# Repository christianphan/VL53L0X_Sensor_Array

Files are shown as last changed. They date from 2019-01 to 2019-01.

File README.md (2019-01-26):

# VL53L0X_Sensor_Array
Schematic and Cad file for array of VL53L0X for proximity sensing applications

This PCB combines 5 VL53L0X sensors adjacent next to each other to detect motion and finger gestures. An I2C multiplexor is also in the PCB to control the 5 sensors over I2C.

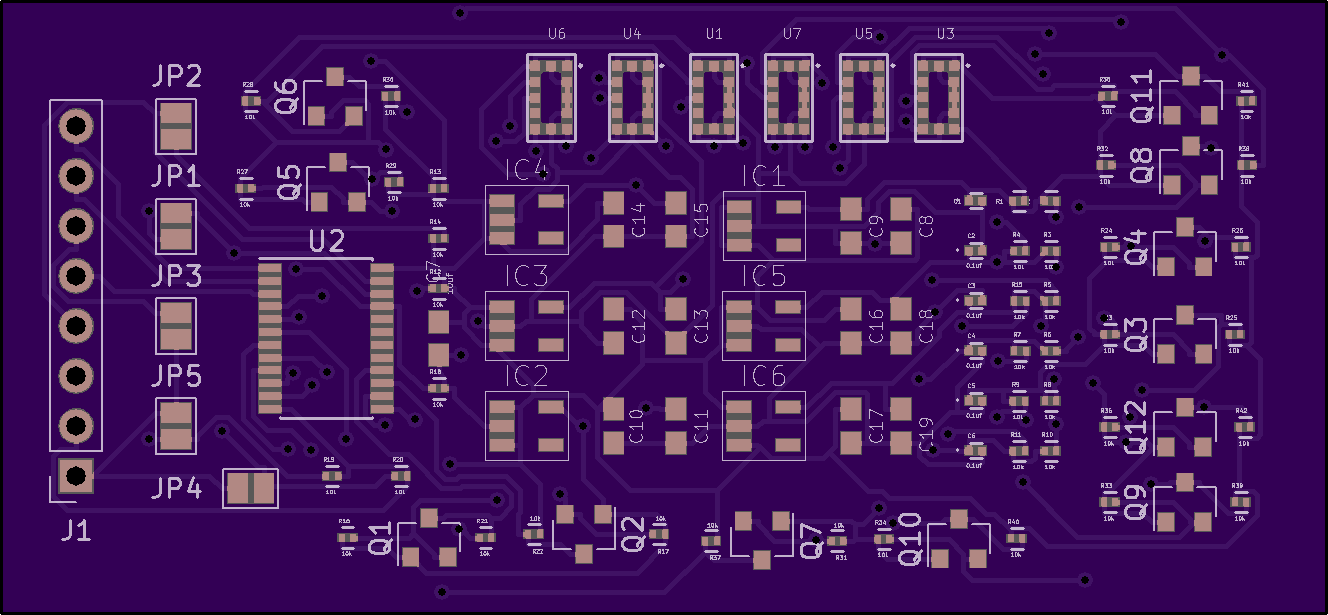
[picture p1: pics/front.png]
Front of PCB


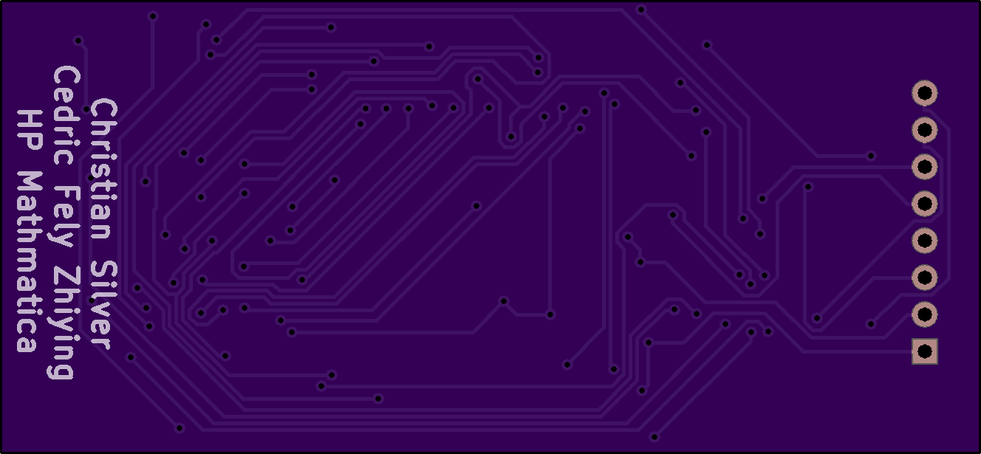
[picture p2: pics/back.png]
Back of PCB


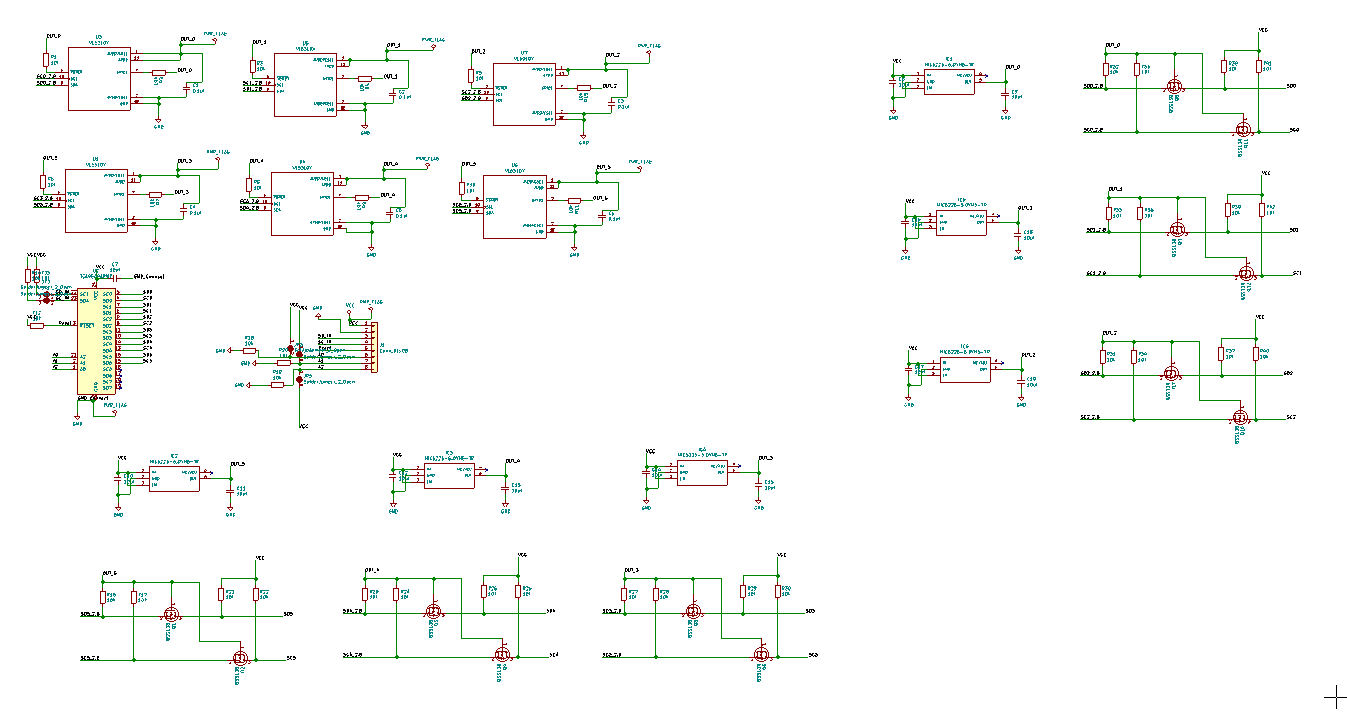
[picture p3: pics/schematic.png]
Schematic


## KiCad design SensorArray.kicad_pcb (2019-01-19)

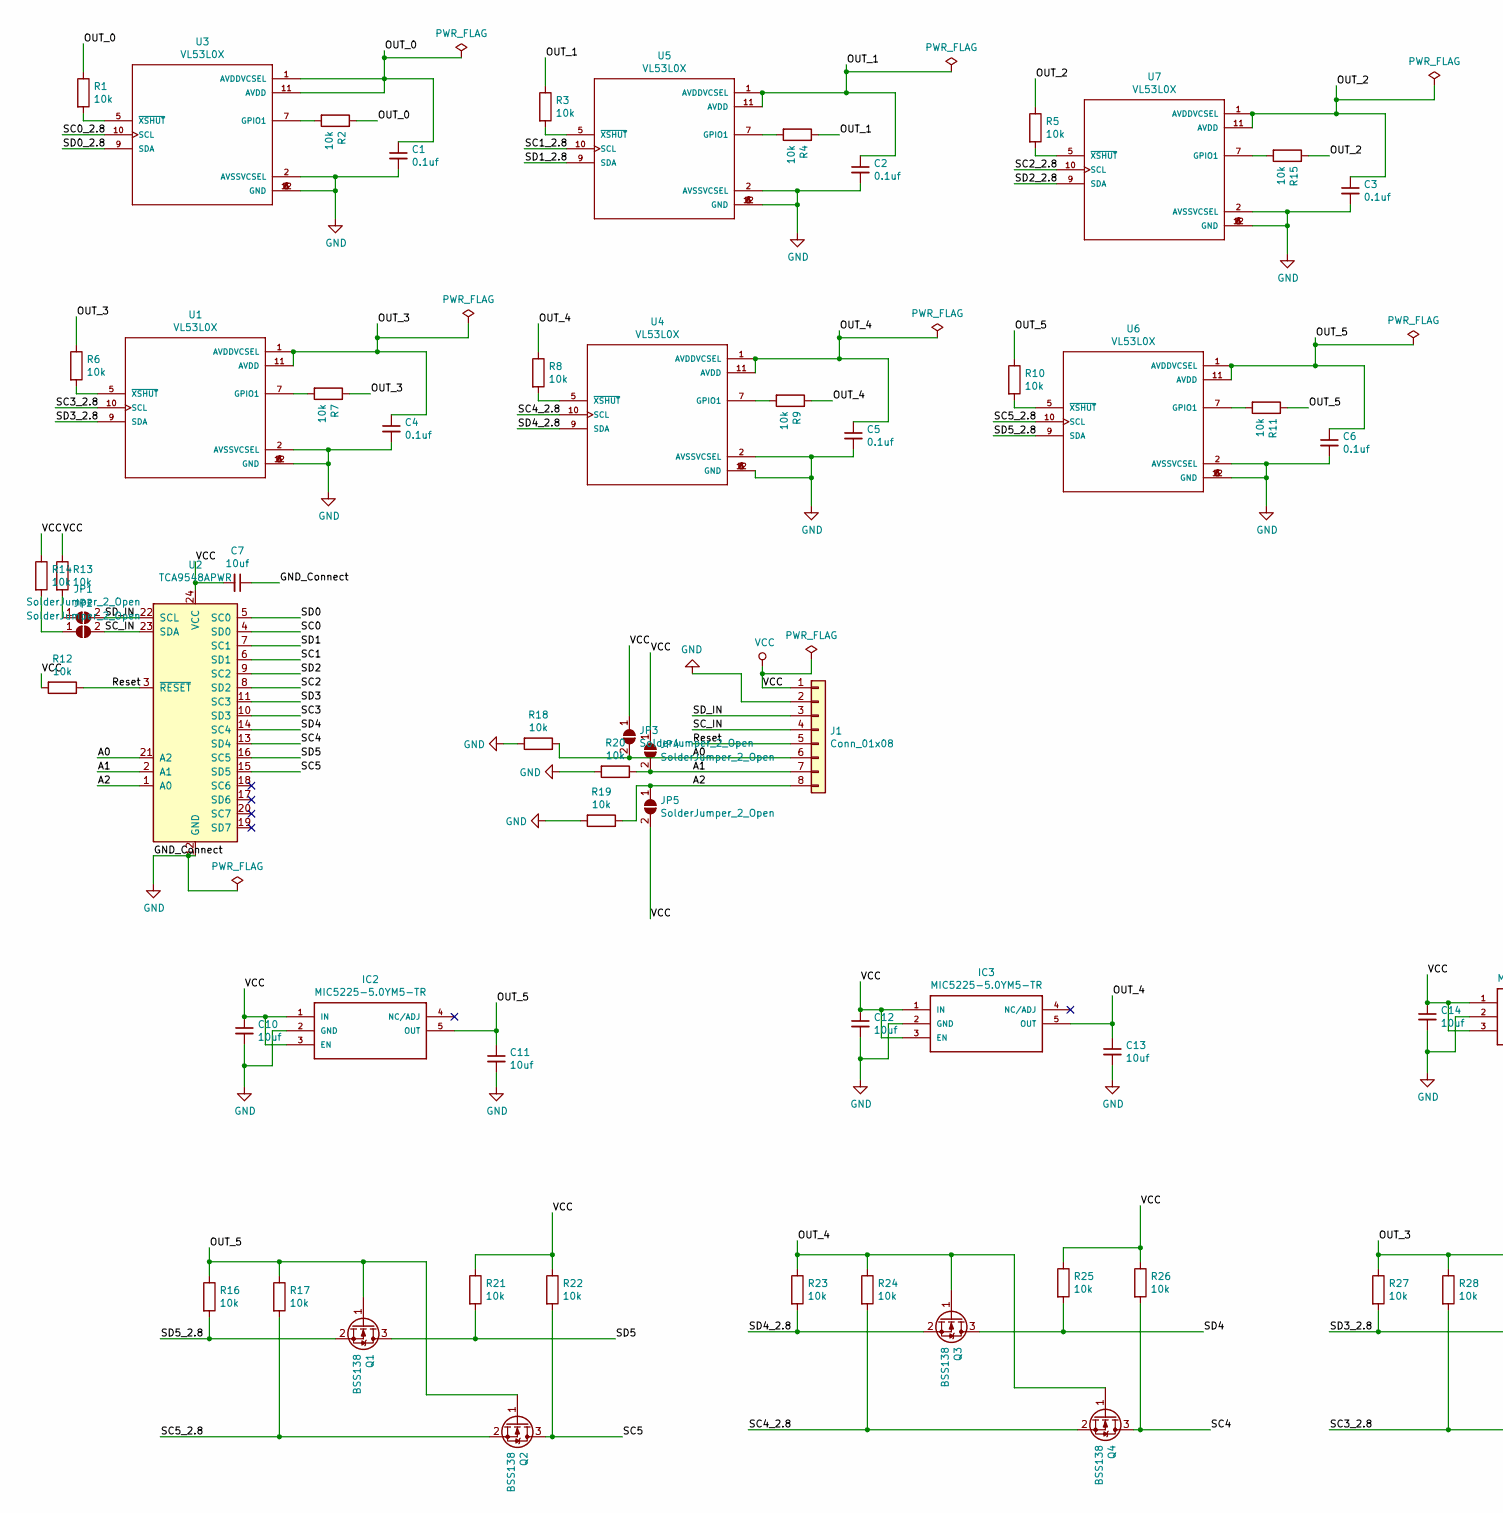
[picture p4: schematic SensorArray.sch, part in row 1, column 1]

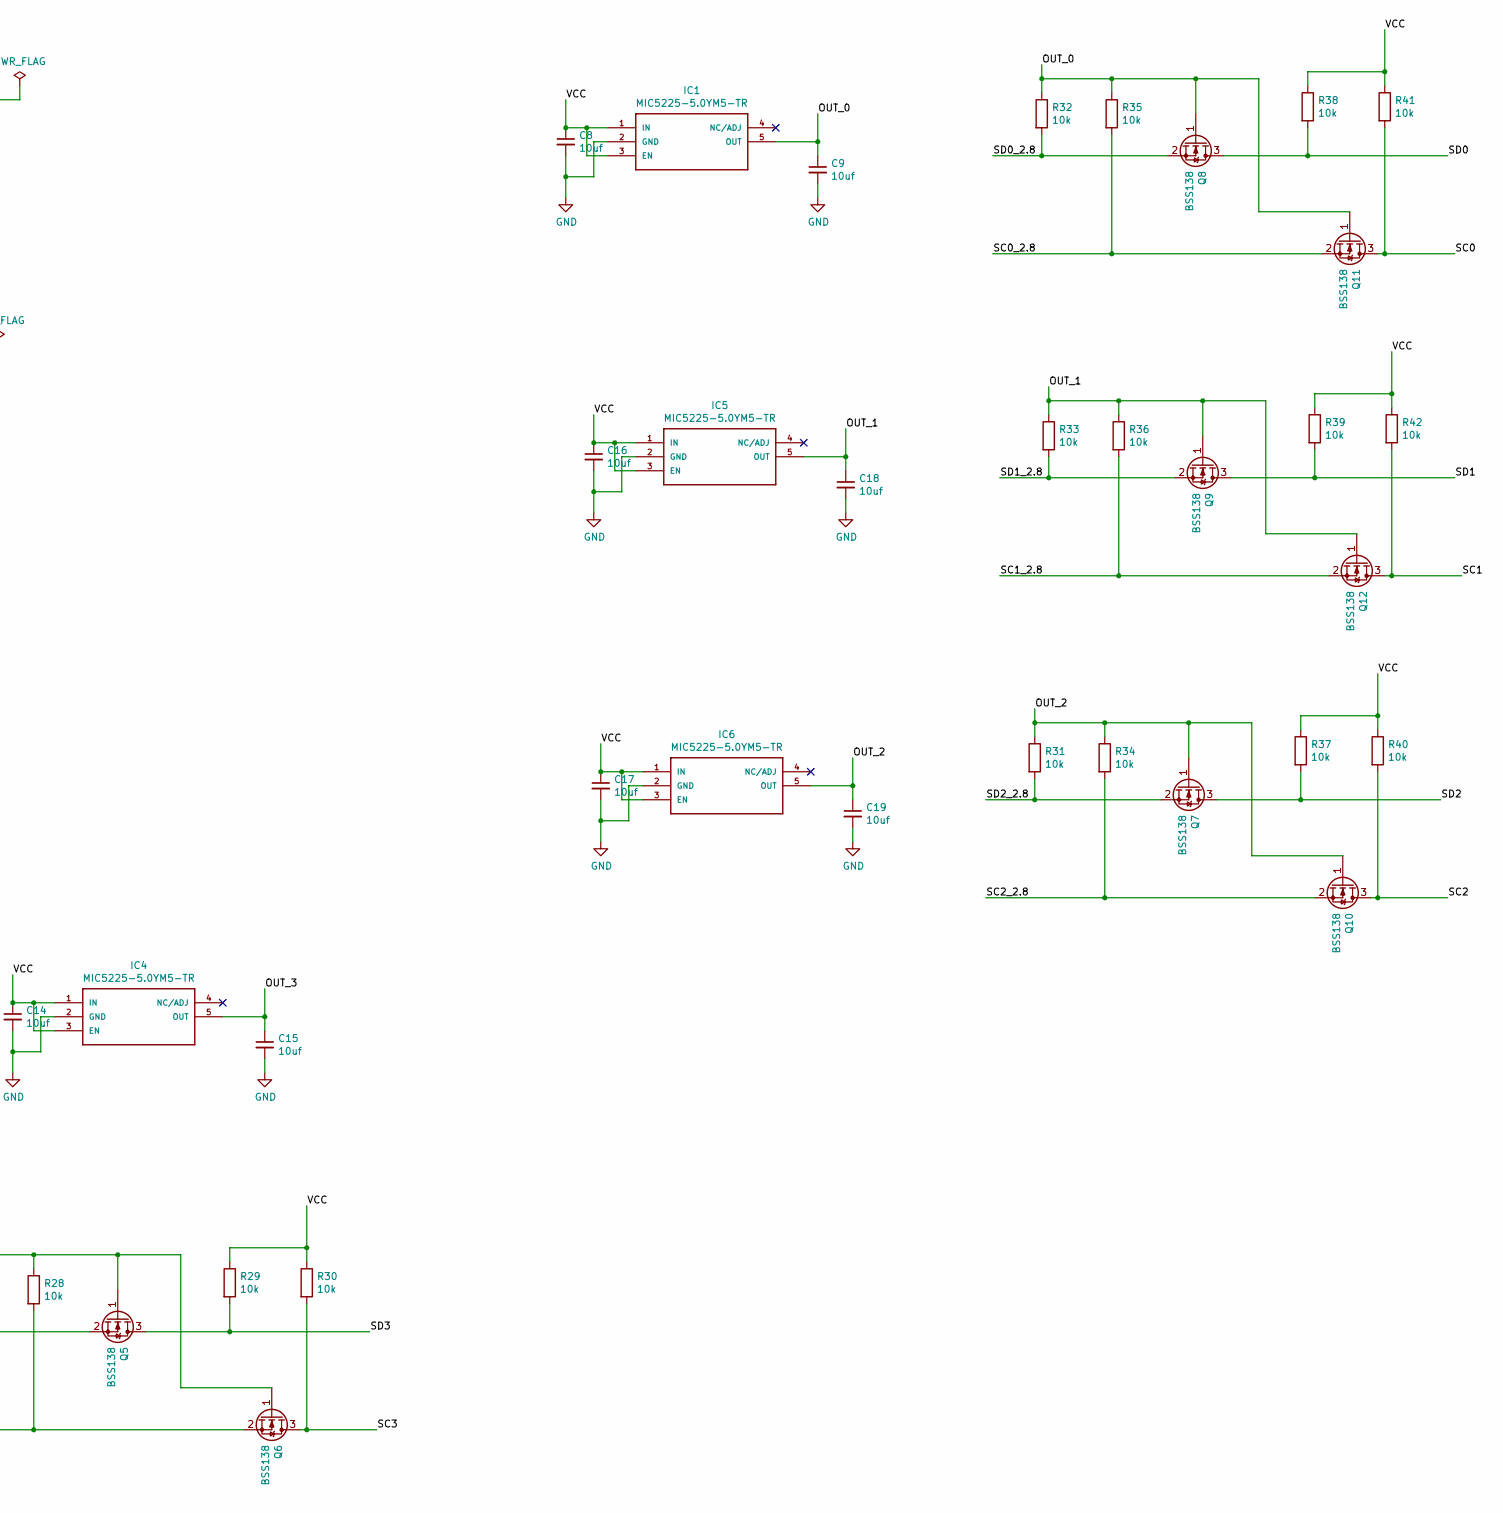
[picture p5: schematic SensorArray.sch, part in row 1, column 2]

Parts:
C1, C2, C3, C4, C5, C6: 0.1uf; CAPC0603X33N
C7, C8, C9, C10, C11, C12, C13, C14, C15, C16, C17, C18, C19: 10uf; 0603-NO
IC1, IC2, IC3, IC4, IC5, IC6: MIC5225-5.0YM5-TR; SOT95P280X130-5N
J1: Conn_01x08; PinSocket_1x08_P2.54mm_Vertical
JP1, JP2, JP3, JP4, JP5: SolderJumper_2_Open; SolderJumper-2_P1.3mm_Open_Pad1.0x1.5mm
Q1, Q2, Q3, Q4, Q5, Q6, Q7, Q8, Q9, Q10, Q11, Q12: BSS138; SOT-23
R1, R2, R3, R4, R5, R6, R7, R8, R9, R10, R11, R12, R13, R14, R15, R16, R17, R18, R19, R20, R21, R22, R23, R24, R25, R26, R27, R28, R29, R30, R31, R32, R33, R34, R35, R36, R37, R38, R39, R40, R41, R42: 10k; RESC0603X26N
U1, U3, U4, U5, U6, U7: VL53L0X; SENSOR_VL53L0X
U2: TCA9548APWR; TSSOP-24_4.4x7.8mm_P0.65mm

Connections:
/A0: J1.6, JP3.2 (B), R18.1, U2.21 (A2)
/A1: J1.7, JP4.2 (B), R20.1, U2.2 (A1)
/A2: J1.8, JP5.1 (A), R19.1, U2.1 (A0)
/OUT_0: C1.1, C9.1, IC1.5 (OUT), Q8.1 (G), Q11.1 (G), R1.1, R2.1, R32.1, R35.1, U3.1 (AVDDVCSEL), U3.11 (AVDD)
/OUT_1: C2.1, C18.1, IC5.5 (OUT), Q9.1 (G), Q12.1 (G), R3.1, R4.1, R33.1, R36.1, U5.1 (AVDDVCSEL), U5.11 (AVDD)
/OUT_2: C3.1, C19.1, IC6.5 (OUT), Q7.1 (G), Q10.1 (G), R5.1, R15.1, R31.1, R34.1, U7.1 (AVDDVCSEL), U7.11 (AVDD)
/OUT_3: C4.1, C15.1, IC4.5 (OUT), Q5.1 (G), Q6.1 (G), R6.1, R7.1, R27.1, R28.1, U1.1 (AVDDVCSEL), U1.11 (AVDD)
/OUT_4: C5.1, C13.1, IC3.5 (OUT), Q3.1 (G), Q4.1 (G), R8.1, R9.1, R23.1, R24.1, U4.1 (AVDDVCSEL), U4.11 (AVDD)
/OUT_5: C6.1, C11.1, IC2.5 (OUT), Q1.1 (G), Q2.1 (G), R10.1, R11.1, R16.1, R17.1, U6.1 (AVDDVCSEL), U6.11 (AVDD)
/Reset: J1.5, R12.1, U2.3 (~RESET)
/SC0: Q11.3 (D), R41.2, U2.4 (SD0)
/SC0_2.8: Q11.2 (S), R35.2, U3.10 (SCL)
/SC1: Q12.3 (D), R42.2, U2.6 (SD1)
/SC1_2.8: Q12.2 (S), R36.2, U5.10 (SCL)
/SC2: Q10.3 (D), R40.2, U2.8 (SD2)
/SC2_2.8: Q10.2 (S), R34.2, U7.10 (SCL)
/SC3: Q6.3 (D), R30.2, U2.10 (SD3)
/SC3_2.8: Q6.2 (S), R28.2, U1.10 (SCL)
/SC4: Q4.3 (D), R26.2, U2.13 (SD4)
/SC4_2.8: Q4.2 (S), R24.2, U4.10 (SCL)
/SC5: Q2.3 (D), R22.2, U2.15 (SD5)
/SC5_2.8: Q2.2 (S), R17.2, U6.10 (SCL)
/SC_IN: J1.4, JP2.2 (B), U2.23 (SDA)
/SD0: Q8.3 (D), R38.2, U2.5 (SC0)
/SD0_2.8: Q8.2 (S), R32.2, U3.9 (SDA)
/SD1: Q9.3 (D), R39.2, U2.7 (SC1)
/SD1_2.8: Q9.2 (S), R33.2, U5.9 (SDA)
/SD2: Q7.3 (D), R37.2, U2.9 (SC2)
/SD2_2.8: Q7.2 (S), R31.2, U7.9 (SDA)
/SD3: Q5.3 (D), R29.2, U2.11 (SC3)
/SD3_2.8: Q5.2 (S), R27.2, U1.9 (SDA)
/SD4: Q3.3 (D), R25.2, U2.14 (SC4)
/SD4_2.8: Q3.2 (S), R23.2, U4.9 (SDA)
/SD5: Q1.3 (D), R21.2, U2.16 (SC5)
/SD5_2.8: Q1.2 (S), R16.2, U6.9 (SDA)
/SD_IN: J1.3, JP1.2 (B), U2.22 (SCL)
GND: C1.2, C2.2, C3.2, C4.2, C5.2, C6.2, C7.1, C8.2, C9.2, C10.2, C11.2, C12.2, C13.2, C14.2, C15.2, C16.2, C17.2, C18.2, C19.2, IC1.2 (GND), IC2.2 (GND), IC3.2 (GND), IC4.2 (GND), IC5.2 (GND), IC6.2 (GND), J1.2, R18.2, R19.2, R20.2, U1.2 (AVSSVCSEL), U1.3 (GND), U1.4 (GND), U1.6 (GND), U1.12 (GND), U2.12 (GND), U3.2 (AVSSVCSEL), U3.3 (GND), U3.4 (GND), U3.6 (GND), U3.12 (GND), U4.2 (AVSSVCSEL), U4.3 (GND), U4.4 (GND), U4.6 (GND), U4.12 (GND), U5.2 (AVSSVCSEL), U5.3 (GND), U5.4 (GND), U5.6 (GND), U5.12 (GND), U6.2 (AVSSVCSEL), U6.3 (GND), U6.4 (GND), U6.6 (GND), U6.12 (GND), U7.2 (AVSSVCSEL), U7.3 (GND), U7.4 (GND), U7.6 (GND), U7.12 (GND)
unnamed: JP1.1 (A), R13.2
unnamed: JP2.1 (A), R14.2
unnamed: R1.2, U3.5 (~XSHUT~)
unnamed: R2.2, U3.7 (GPIO1)
unnamed: R3.2, U5.5 (~XSHUT~)
unnamed: R4.2, U5.7 (GPIO1)
unnamed: R5.2, U7.5 (~XSHUT~)
unnamed: R6.2, U1.5 (~XSHUT~)
unnamed: R7.2, U1.7 (GPIO1)
unnamed: R8.2, U4.5 (~XSHUT~)
unnamed: R9.2, U4.7 (GPIO1)
unnamed: R10.2, U6.5 (~XSHUT~)
unnamed: R11.2, U6.7 (GPIO1)
unnamed: R15.2, U7.7 (GPIO1)
VCC: C7.2, C8.1, C10.1, C12.1, C14.1, C16.1, C17.1, IC1.1 (IN), IC1.3 (EN), IC2.1 (IN), IC2.3 (EN), IC3.1 (IN), IC3.3 (EN), IC4.1 (IN), IC4.3 (EN), IC5.1 (IN), IC5.3 (EN), IC6.1 (IN), IC6.3 (EN), J1.1, JP3.1 (A), JP4.1 (A), JP5.2 (B), R12.2, R13.1, R14.1, R21.1, R22.1, R25.1, R26.1, R29.1, R30.1, R37.1, R38.1, R39.1, R40.1, R41.1, R42.1, U2.24 (VCC)

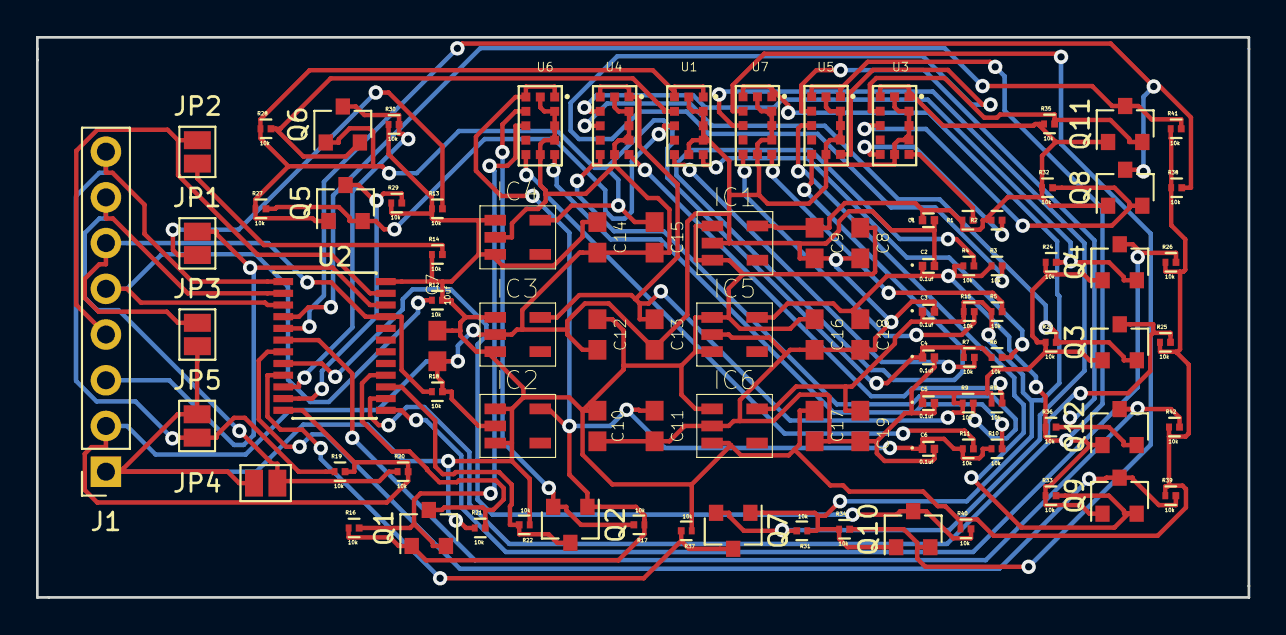
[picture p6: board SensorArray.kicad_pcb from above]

Board: 2 copper layers, 67.3 x 31.1 mm, 92 parts (0 on the bottom side), 52 nets.

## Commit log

2018-11-10 Week 6 Progress
    [SensorArray.kicad_pcb, SensorArray.sch]
2018-11-14 More Thinks finished week 7
    [SensorArray.kicad_pcb, SensorArray.sch]
2018-11-20 updated schematic and pcb layout
    [SensorArray.kicad_pcb, SensorArray.sch]
2019-01-19 pcb made
    [SensorArray-B.Cu.gbr, SensorArray-B.Mask.gbr, SensorArray-B.Paste.gbr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]
2019-01-22 pcb image added
2019-01-26 schematic image
